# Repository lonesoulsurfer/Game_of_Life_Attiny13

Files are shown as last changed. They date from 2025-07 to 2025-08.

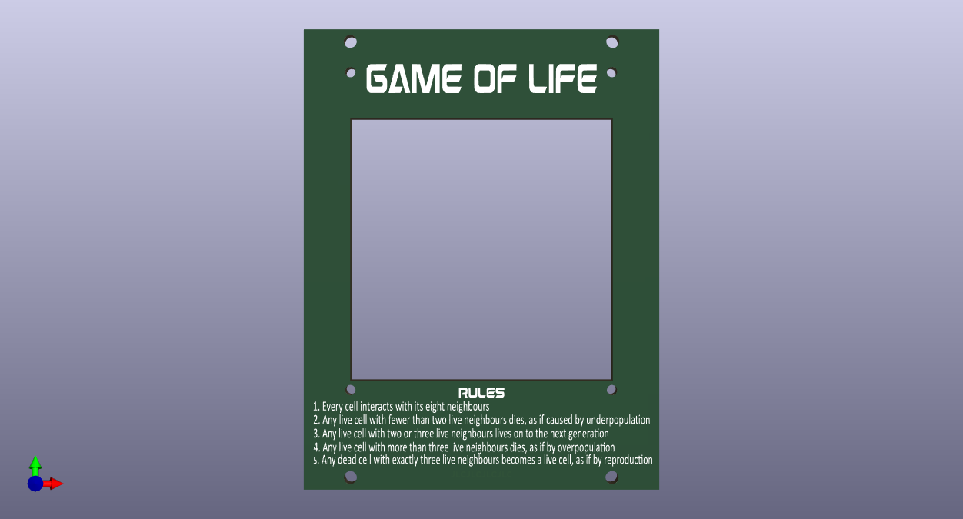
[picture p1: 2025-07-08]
Front Panel Design/Kicad - Front Panel/Game of Life/Game of Life - 3D Image.png

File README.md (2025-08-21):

# Game_of_Life_Attiny13

GOL

The Game of Life is a cellular automation created by mathamatician John Conway. It's what is known as a zero player game, meaning that its evolution and game play is determined by its initial state and requires no further input. You interact with the Game of Life by creating an initial configuration and observing how it evolves.

The game itself is based on a few, simple, mathematical rules consisting of a grid of cells that can either live, die or multiply. When the game is run, the cells can give the illusion (or are they alive...) that they are alive which is what makes this game so interesting.

There's plenty of information on the Internet about the Game of Life. If you are interested in learning more then definitely check out the links belowe which have some great resources and info.

This build is based on another Instructable by Sanuki Udon who created the code and project.

My contribution is; I created a PCB and front panel for the project and have tweaked some of the parameters in the sketch to make the game run faster and longer.  I also added a dufusser to the front of the LED's which I think gives more of a feeling that the cells are alive.

Youtube Vid
https://youtu.be/9KQFAfuK4dU

Instructables (Step by step guide on how to build your own
https://www.instructables.com/Conways-Game-of-Life-Running-on-an-ATtiny13/

Original Build on Instructables
https://www.instructables.com/Conways-Life-of-Life-of-1616-Cells-Made-With-ATtin/

Wikipedia
https://en.wikipedia.org/wiki/Conway%27s_Game_of_Life

Play Game of Life on line
https://playgameoflife.com/

Building a computer in the Game of Life
https://www.nicolasloizeau.com/gol-computer

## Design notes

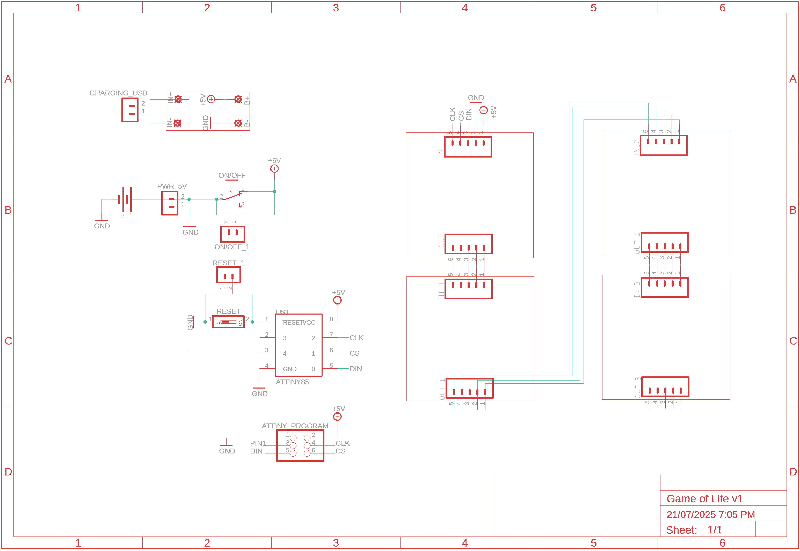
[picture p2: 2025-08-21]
Schematic.png

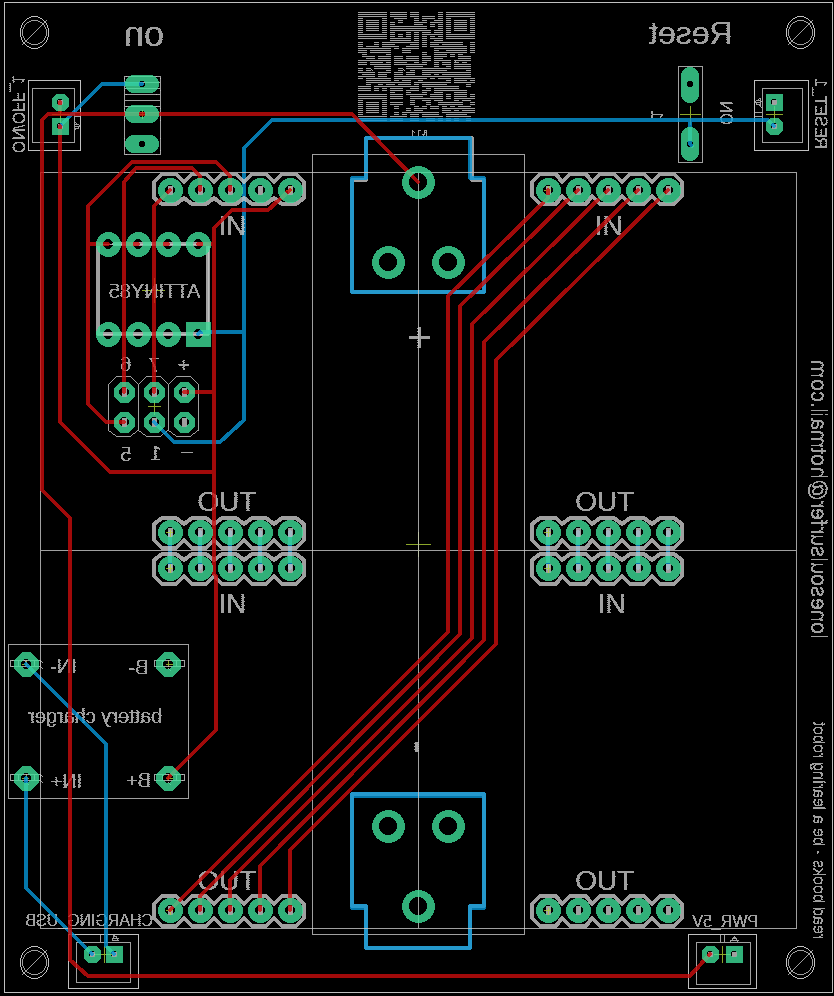
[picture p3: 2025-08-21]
PCB - Image.png

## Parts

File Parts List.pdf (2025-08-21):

Part | Type | Qty | Link | Image
Charging Module | Micro USB | 1 | Link (https://vi.aliexpress.com/item/1005006274938832.html?sourceType=1)
USB C connector | Screw fixing plate | 1 | Link (https://vi.aliexpress.com/item/1005006485428578.html)
18560 Battery | 1 | Link (https://vi.aliexpress.com/w/wholesale-18560-battery.html)
18650 Battery Holder | PCB Mount | 1 | Link (https://www.aliexpress.com/item/1005006949570816.html?curPageLogUid=NFbCAQQCouBf)
Connector Male & Female | JST 2.0 PH 2-Pin | Max 4 | Link (https://vi.aliexpress.com/item/32665588344.html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)

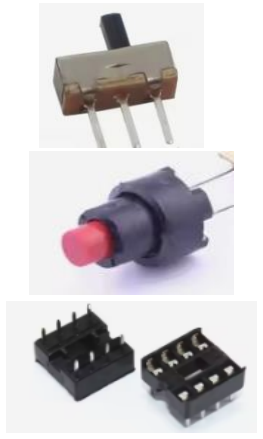
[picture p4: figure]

On/Off Switch | slide - PCB Mount | 1 | Link (https://vi.aliexpress.com/w/wholesale-on%2525252doff-mini-1-Way-2-Band-Slide-Switch-PCB-Mount-.html)
Monentary Switch | SKRCADD010 | 1 | Link (https://www.aliexpress.com/w/wholesale-SKRCADD010.html?spm=a2g0o.productlist.search.0)
8 Pin IC Socket | DIP-8 | 1 | Link (https://vi.aliexpress.com/w/wholesale-8-pin-ic-socket.html?spm=a2g0o.productlist.search.0)
Attiny13A | Through Hole | 1 | Link (https://vi.aliexpress.com/w/wholesale-attiny-13A.html?spm=a2g0o.productlist.search.0)
8X* Led Matrix | MAX7219 | 4 | Link (https://vi.aliexpress.com/item/1005006534411895.html?gatewayAdapt=glo2vnm)
Male Header Pins | Single Row | 5 Pins X 4 Link (https://vi.aliexpress.com/w/wholesale-male-header-pins.html?spm=a2g0o.detail.search.0)

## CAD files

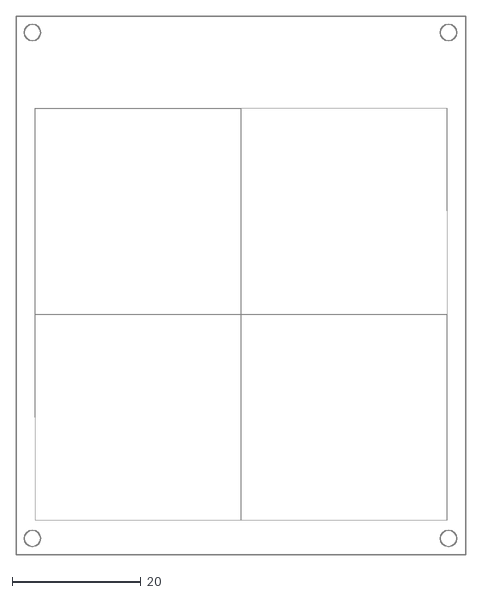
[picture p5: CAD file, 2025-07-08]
Front Panel Design/Game of Life pcb.dxf
70.0 x 83.8

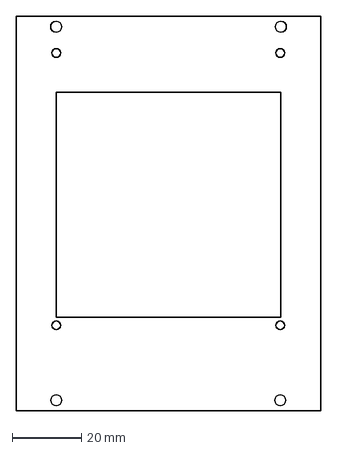
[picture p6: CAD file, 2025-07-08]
Front Panel Design/Game of Life - Fusion.dxf
88.0 x 114.0 mm

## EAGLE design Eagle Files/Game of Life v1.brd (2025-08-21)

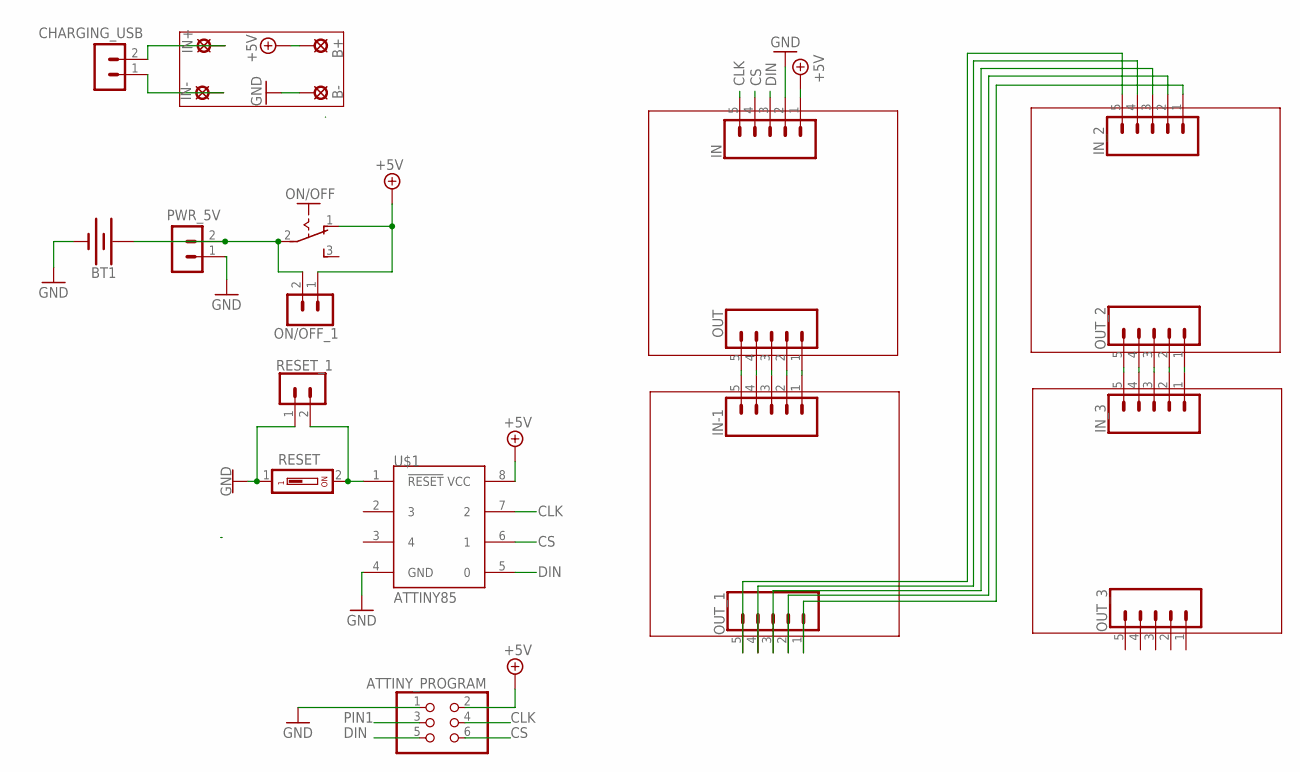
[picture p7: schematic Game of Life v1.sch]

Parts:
ATTINY_PROGRAM: PINHD-2X3; 2X03
B+: LSP11
B-: LSP11
BT1: BATTERY-18650; BATTERY_18650-HOLDER
CHARGING_USB: B2B-PH-K-S
IN: CONN_05; 1X05
IN+: LSP11
IN-: LSP11
IN-1: CONN_05; 1X05
IN_2, IN_3: CONN_05; 1X05
ON/OFF: M251
ON/OFF_1: B2B-PH-K-S
OUT: CONN_05; 1X05
OUT_1, OUT_2, OUT_3: CONN_05; 1X05
PWR_5V: B2B-PH-K-S
RESET: DS01; DS-01
RESET_1: B2B-PH-K-S
U$1: ATTINY85; 8P3

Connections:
+5V: ATTINY_PROGRAM.2, B+.MP, IN.1, ON/OFF.1 (O), ON/OFF_1.1, U$1.8 (VCC)
CLK: ATTINY_PROGRAM.4, IN.5, U$1.7 (2)
CS: ATTINY_PROGRAM.6, IN.4, U$1.6 (1)
DIN: ATTINY_PROGRAM.5, IN.3, U$1.5 (0)
GND: ATTINY_PROGRAM.1, B-.MP, BT1.GND@1 (-), IN.2, PWR_5V.1, RESET.1, RESET_1.1, U$1.4 (GND)
unnamed: BT1.PWR@1 (+), ON/OFF.2, ON/OFF_1.2, PWR_5V.2
unnamed: CHARGING_USB.2, IN+.MP
unnamed: IN-1.1, OUT.1
unnamed: IN-1.2, OUT.2
unnamed: IN-1.3, OUT.3
unnamed: IN-1.4, OUT.4
unnamed: IN-1.5, OUT.5
unnamed: IN_3.1, OUT_2.1
unnamed: IN_3.2, OUT_2.2
unnamed: IN_3.3, OUT_2.3
unnamed: IN_3.4, OUT_2.4
unnamed: IN_3.5, OUT_2.5
unnamed: IN_2.1, OUT_1.1
unnamed: IN_2.2, OUT_1.2
unnamed: IN_2.3, OUT_1.3
unnamed: IN_2.5, OUT_1.5
unnamed: IN_2.4, OUT_1.4
unnamed: CHARGING_USB.1, IN-.MP
PIN1: ATTINY_PROGRAM.3, RESET.2, RESET_1.2, U$1.1 (!RESET)

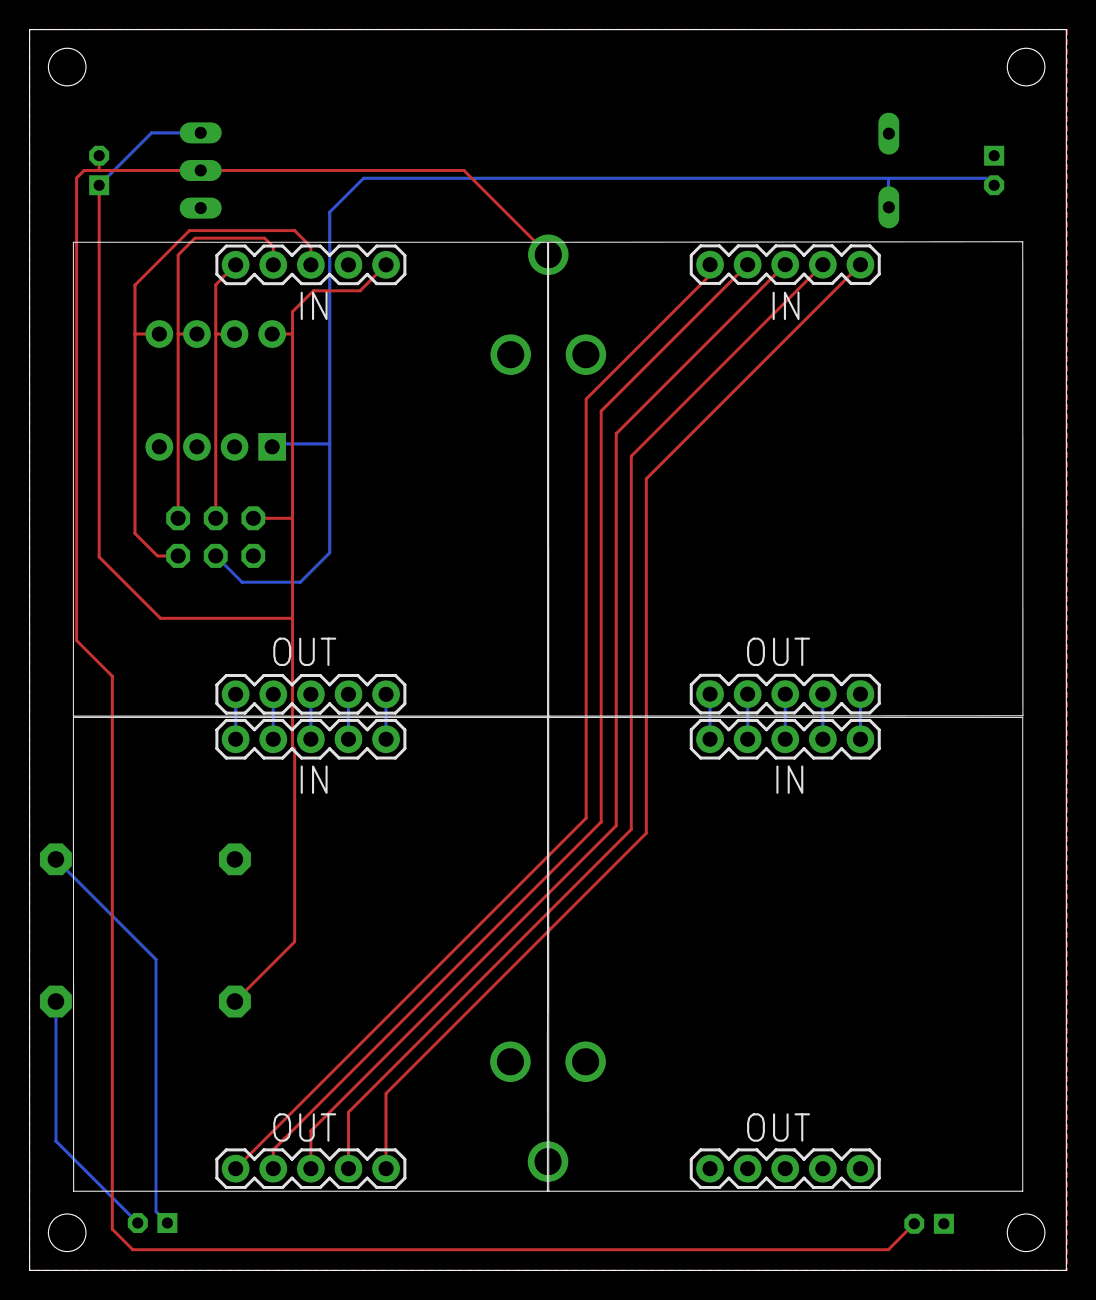
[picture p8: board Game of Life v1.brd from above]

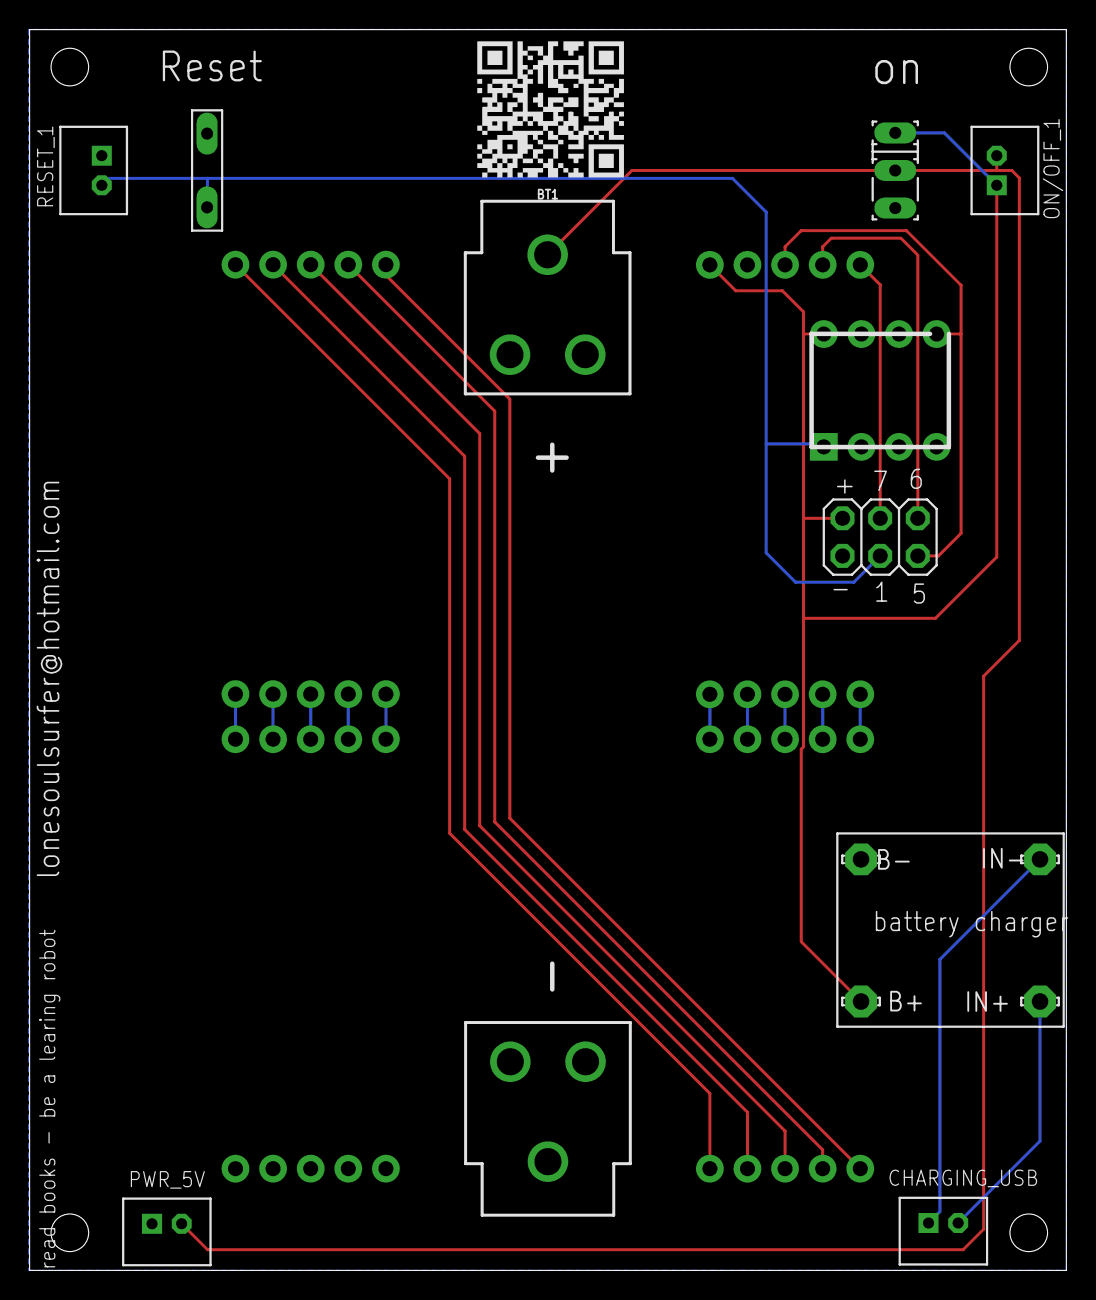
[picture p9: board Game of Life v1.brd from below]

Board: 2 copper layers, 70.0 x 83.8 mm, 21 parts (13 on the bottom side), 24 nets.

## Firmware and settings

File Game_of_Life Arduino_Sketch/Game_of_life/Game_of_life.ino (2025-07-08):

/*

  @file ATtiny13A_Game_of_Life_16x16.ino

  Memo:
  Arduino IDE 1.8.2 + https://mcudude.github.io/MicroCore/package_MCUdude_MicroCore_index.json

  @brief Game of Life
  References:
  https://en.wikipedia.org/wiki/Conway%27s_Game_of_Life

  @author Kei Takagi
  @date 2017.5.5

  Copyright (c) 2017 Kei Takagi
  Released under the MIT license
  http://opensource.org/licenses/mit-license.php

*/

#define Max7219PinCLK  PB2
#define Max7219PinCS   PB1
#define Max7219PinDIN  PB0

#define HIGHT  16
#define WIDTH  16
#define Max7219_HIGHT   8
#define Max7219_WIDTH   8

#define GEBERATIONS 1000
#define SPEED       100
#define STARTY      1

byte Generations = 21;
word cellCount = 0;

word DotArea[HIGHT + 2] = {
  // Hertz oscillator
  0b0000000000000000,
  0b0000000000000000,
  0b0000000000000000,
  0b0000000000000000,
  0b0000000000000000,
  0b0000000000000000,
  0b0000000000000000,
  0b0000000000000000,
  0b0000000000000000,
  0b0000000000000000,
  0b0010000000000000,
  0b1010000000000000,
  0b0110000000000000,
  0b0000000000000000,
  0b0000000000000000,
  0b0000000000000000,
  0b0000000000000000,
  0b0000000000000000
};

void setup() {
  // Setup MAX7219
  DDRB = 1 << Max7219PinCLK | 1 << Max7219PinCS | 1 << Max7219PinDIN;
  Write_Max7219(0x09, 0x00, 0x00, 0x00, 0x00); // using an led matrix (not digits)
  Write_Max7219(0x0A, 0x07, 0x07, 0x07, 0x07); // Brightness 0x00-0x0F 0x01=dark .... 0x0F=bright
  Write_Max7219(0x0B, 0x07, 0x07, 0x07, 0x07); // Scan limit = 7
  Write_Max7219(0x0C, 0x01, 0x01, 0x01, 0x01); // Normal operation mode
  Write_Max7219(0x0F, 0x00, 0x00, 0x00, 0x00); // Disable display test
}

void loop() {
  byte i, j, c, d, ans;
  word calcArea[3];

  if (Generations == 0) {
    DotArea[0] = 0x0000;
    DotArea[HIGHT + 1] = 0x0000;

    for (i = 0; i < HIGHT; i++) {
      DotArea[i + 1] = 0x0000;
      for (j = 0; j < WIDTH; j++) {
        if (analogRead(PB3) % 2 == 0)DotArea[i + 1] |= (0x0001 << j);
      }
    }
    Generations = GEBERATIONS;
  }
  Generations--;

  for (i = 0; i < Max7219_HIGHT; i++) {
    //Display
    Write_Max7219(i + 1,
                  DotArea[i + STARTY] >> 8 ,

                  DotArea[i + STARTY],
                  DotArea[i + Max7219_HIGHT + STARTY] >> 8 ,
                  DotArea[i + Max7219_HIGHT + STARTY]);
  }
  delay(SPEED);

  DotArea[HIGHT + 1] = DotArea[1];
  DotArea[0]  = DotArea[HIGHT];

  calcArea[0] = DotArea[0];
  calcArea[1] = DotArea[1];
  calcArea[2] = DotArea[2];

  //GAME OF LIFE
  cellCount = 0;
  for (i = 1; i < (HIGHT + 1); i++) {
    DotArea[i] = 0x0000;
    for (j = 0; j < WIDTH; j++) {
      c = j - 1 < 0 ? WIDTH - 1 : j - 1;
      d = j + 1 >= WIDTH ? 0 : j + 1;
      ans = ((calcArea[0] >> c) & 0x0001)
            + ((calcArea[0] >> j) & 0x0001)
            + ((calcArea[0] >> d) & 0x0001)
            + ((calcArea[1] >> c) & 0x0001)
            + ((calcArea[1] >> d) & 0x0001)
            + ((calcArea[2] >> c) & 0x0001)
            + ((calcArea[2] >> j) & 0x0001)
            + ((calcArea[2] >> d) & 0x0001);
      if ( (calcArea[1] >> j) & 0x0001) {
        if (ans == 2) {
          DotArea[i] |= 0x0001 << j;
          cellCount++;
        }
      }
      if (ans == 3) {
        DotArea[i] |= 0x0001 << j;
        cellCount++;
      }
    }
    calcArea[0] = calcArea[1];
    calcArea[1] = calcArea[2];
    calcArea[2] = DotArea[i + 2];
  }
  if (cellCount < 5 & Generations > 5)Generations = 5;
}

void Write_Max7219(byte address, short in_01, short in_02 , short in_03, short in_04)
{
  PORTB = 0x00;
  shiftOut( Max7219PinDIN, Max7219PinCLK, MSBFIRST, address );
  shiftOut( Max7219PinDIN, Max7219PinCLK, MSBFIRST, in_01 );
  shiftOut( Max7219PinDIN, Max7219PinCLK, MSBFIRST, address );
  shiftOut( Max7219PinDIN, Max7219PinCLK, MSBFIRST, in_02 );
  shiftOut( Max7219PinDIN, Max7219PinCLK, MSBFIRST, address );
  shiftOut( Max7219PinDIN, Max7219PinCLK, MSBFIRST, in_03 );
  shiftOut( Max7219PinDIN, Max7219PinCLK, MSBFIRST, address );
  shiftOut( Max7219PinDIN, Max7219PinCLK, MSBFIRST, in_04 );
  PORTB =  1 << Max7219PinCS;
}

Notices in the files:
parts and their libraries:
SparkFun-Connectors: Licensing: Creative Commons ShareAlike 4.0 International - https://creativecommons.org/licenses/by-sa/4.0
